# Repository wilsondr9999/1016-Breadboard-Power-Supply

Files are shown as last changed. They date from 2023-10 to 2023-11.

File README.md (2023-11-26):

# BreadBrick
#### The breadboard power supply *with flair*

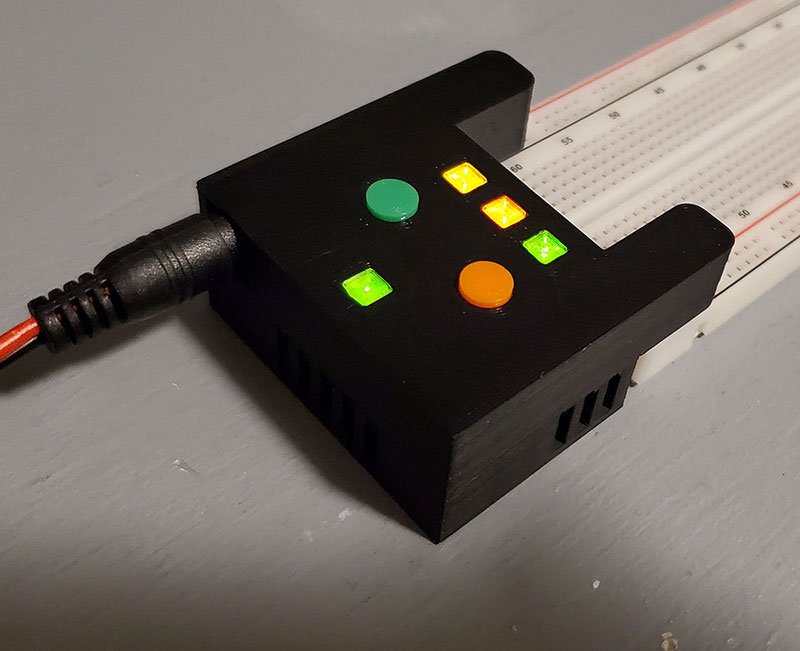
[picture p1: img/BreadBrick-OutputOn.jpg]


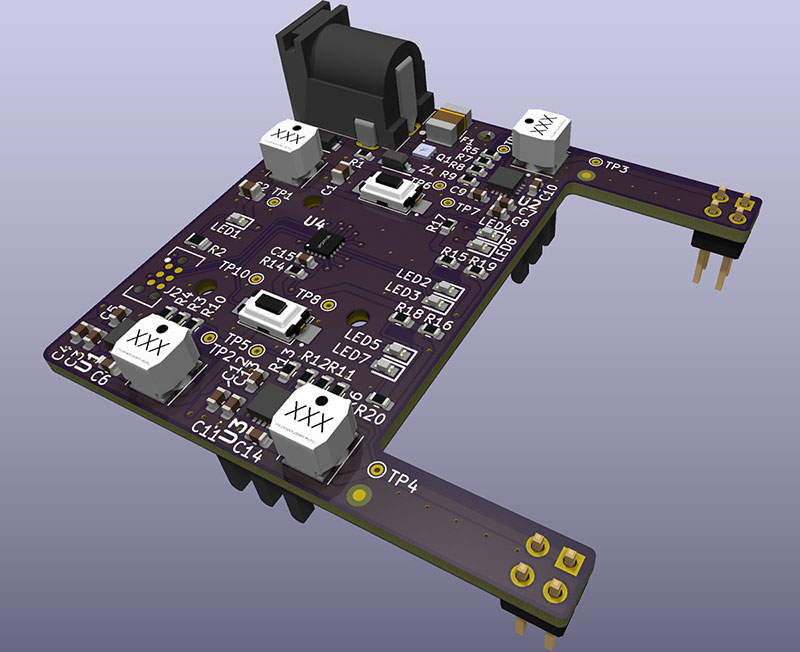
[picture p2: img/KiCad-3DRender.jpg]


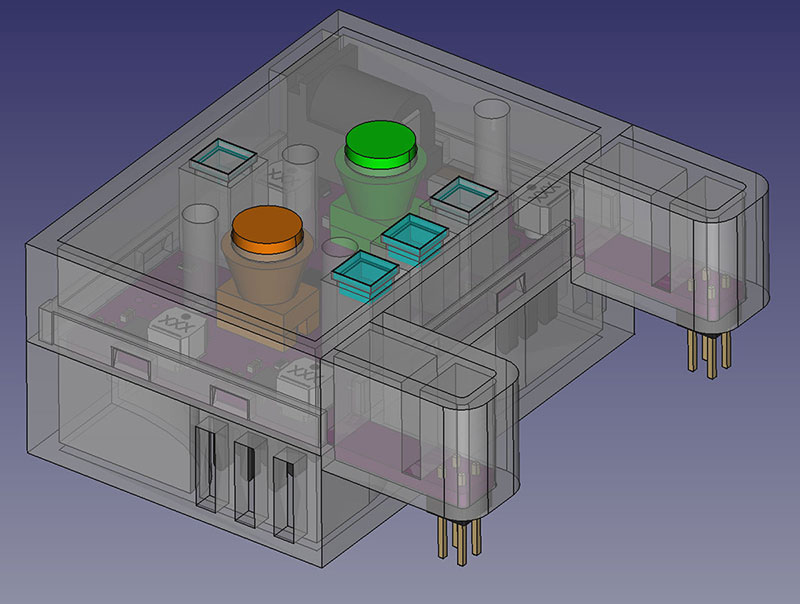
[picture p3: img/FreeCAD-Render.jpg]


## Why Another Breadboard Power Supply?

There's a million of these things out there, and they all work pretty much the same.  They plug in on one end of the breadboard and supply power to the voltage rails.  Many do 5V only, some have switchable 5V / 3.3V using jumpers.  Many use linear power regulators which are not terribly efficient.  Many have substantial voltage droop.  Many can't supply very much current.

I wanted something with a bit more, ummm, pizazz.  I wanted a case, not a bare PCB.  I wanted the ability to set the voltage independently for each rail, indicator lights for what voltages are set, up to 2A / 10W on each rail, and protection circuitry for those times when you plug something into the breadboard backwards.  And some efficiency so the thing doesn't get hot.

It took me a while, but I did it.

## Design

The design of the unit is actually not too complicated, there is an input section for protection and filtering, three [Texas Instruments TPS62130A](https://www.ti.com/product/TPS62130A) switching buck regulator circuits, two for the two power rails, and a 3rd that generates a dedicated 3.3V for the MCU, and an MCU section that uses the [STM32C011F4](https://www.st.com/en/microcontrollers-microprocessors/stm32c011f4.html).  The MCU is used to get user input from the buttons, drive the indicator LEDs, and control and monitor the rail regulators.

All components were selected for reasonable cost and wide availability.  However, the design is at the limit of what a hobbyist can successfully assemble.  While no parts smaller than 0603 are used, some ICs are QFN, and hand soldering these parts can be difficult for the hobbyists.  This board can be assembled by board assembly services at a reasonable cost.

## Tools and Software

Circuit design, schematics, and PCB layout were all done with [KiCad](https://www.kicad.org/).  Design of the case was done in [FreeCAD](https://www.freecad.org/).  Software code for the STM32C0 was written, compiled, and debugged using the [STM32CubeIDE](https://www.st.com/en/development-tools/stm32cubeide.html) development environment.

## Licensing

Several different licenses apply to this repository and the files within.

All schematics and circuit board designs in the project (all KiCad files), as well as all case designs (all FreeCAD files) are licensed under the [CERN Open Hardware License Version 2 - Strongly Reciprocal (CERN-OHL-S)](LICENSE-CERN-OHL-S).

All software and firmware code in the project (all ) are licensed under the [GNU Affero General Public License v3.0 (AGPL 3.0)](LICENSE-AGPL).

Documentation, Bill of Materials, pictures, and documentation (i.e. all other files not covered by the other two licenses above) are licensed under the [Creative Commons Attribution Share Alike 4.0 International License (CC-BY-SA-4.0)](LICENSE-CC-BY-SA-4.0).

These licenses form a very restrictive license for this design and this project.  This is done specifically for a reason.  That reason is that this project is for the hobbyist, and the hobbyist only.  It is for those people who want to have one of these units to be able to make one for themselves.  What it is not for is for some no-name company to produce thousands of them and make money when they had nothing to do with the design and the hard work.  These licenses force anyone who wants to do that to share anything and everything that they derive from this work so that the community and the hobbyists have it also.

## Specifications
- Input Voltage: 7V - 17V
- DC Barrel Jack: 2.5mm ID x 5.5mm OD, Center pin is positive (+)
- Max Input Current: 2A
- Output Voltage: 5V +/- 0.05V, 3.3V +/- 0.05V, switchable per rail
- Output Voltage Ripple: 25 mV at 2A load
- Max Output Current: 2A per rail
- Typical Efficiency: 88.0% at 12V input and 5V / 1A output
- Worst-Case Efficiency: 84.0% at 17V input and 3.3V / 2A output
- Worst-Case heat sink temperature: 51.1 C at full 2A load

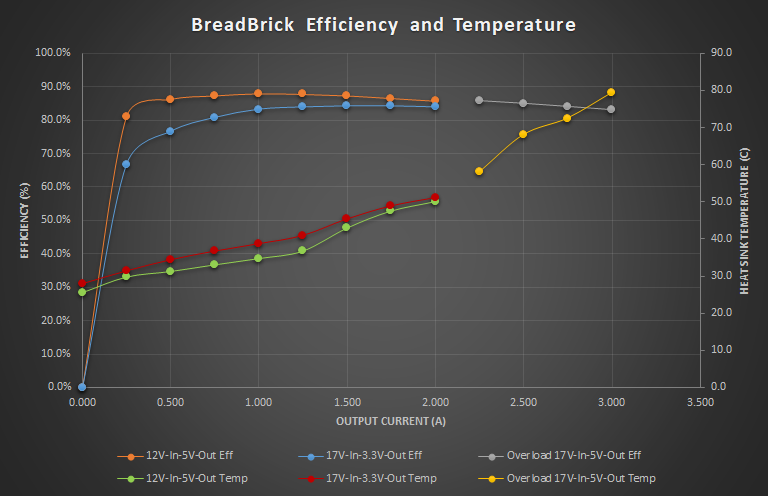
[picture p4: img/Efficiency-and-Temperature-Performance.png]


## How To Build
#### Ordering the PCB
To order this PCB, you can submit the [Fabrication Exports.zip](KiCAD%20Project/Fabrication%20Exports/Fabrication%20Exports.zip) file (located in [KiCAD Project/Fabrication Exports/](KiCAD%20Project/Fabrication%20Exports/)) to your favorite PCB manufacturing company.  This is a 2 layer board so costs should be low.
#### Ordering the Stencil
If you want to assemble the board yourself, especially if you want to use a reflow oven, you can order a stencil using the [1016 Breadboard Power Supply-F_Paste.gbr](KiCAD%20Project/Fabrication%20Exports/1016%20Breadboard%20Power%20Supply-F_Paste.gbr) gerber layer.  This layer includes 2.5mm alignment pins on two corners, these are sized and located to fit on the [solder stencil jig](FreeCAD%20Project/Parametric%20Solder%20Stencil%20Jig/1016%20v2%20Parametric%20Solder%20Stencil%20Jig.3mf) that can be 3D-printed.  If instead you are having a PCB manufacturer assemble the SMD components for you, you do not need the solder stencil.
#### Ordering Parts
If you're assembling yourself, you'll need to order parts.  The [1016 Breadboard Power Supply.csv](KiCAD%20Project/BOM/1016%20Breadboard%20Power%20Supply.csv) file located in the [KiCAD Project/BOM/](KiCAD%20Project/BOM/) folder contains all parts and manufacturer part numbers.
#### Assembling the PCB
The [ibom.html](KiCAD%20Project/BOM/ibom.html) file located in the [KiCAD Project/BOM/](KiCAD%20Project/BOM/) folder is generated from the [KiCad Interactive BOM plug-in](https://github.com/openscopeproject/InteractiveHtmlBom), and can help you mark which parts have been placed on the board prior to reflow.

Be very careful placing the LEDs.  The silkscreen marks pin 1 of the LED, but in accordance with the [datasheets](Datasheets/[DS-006]%20Wurth%20Elektronik%20150060VS75003.pdf) for the Wurth Elektronik LEDs, the pin 1 marking is NOT the cathode as would normally be expected.

After placing components, reflow the board in a reflow oven, hot plate, or use a hot air station.
#### Through-Hole Components
You will need to solder three through-hole components -- the DC power jack (PJ-102B), and the 2x2 pin headers (J3/J4).
#### Heat Sinks
The two heat sinks are glued onto the back side of the board using thermal adhesive.  Note that this is thermal adhesive (glue), not just an ordinary thermal compound or thermal paste.  The adhesive is required, there is no other mechanical support for the heat sinks.  I successfully used the [Gennel G109 Thermal Conductive Glue](https://www.amazon.com/dp/B072MSXHJD?psc=1&ref=ppx_yo2ov_dt_b_product_details).
#### 3D Printing the Case
The case can be 3D printed using the [Case Top-Bottom.3mf](FreeCAD%20Project/Case/STL/Case%20Top-Bottom.3mf), [Button.3mf](FreeCAD%20Project/Case/STL/Button.3mf), and [LED Lens.3mf](FreeCAD%20Project/Case/STL/LED%20Lens.3mf) files and [PrusaSlicer](https://www.prusa3d.com/page/prusaslicer_424/), or if you want to slice the .stl files yourself, the .stl files are also included in the [FreeCAD Project/Case/STL](FreeCAD%20Project/Case/STL/) folder.  Printing settings are as follows:
- 0.12mm Layer Height
- 0.4mm Nozzle
- PETG material, do not use PLA.  The snap-together design needs a flexible plastic, PLA is too brittle and will likely break when trying to snap together the case.  Also, PLA is not as temperature-resistant as PETG, and the heat sinks could cause problems with PLA.
- For the LED lenses, you will need a clear PETG filament.  I have had good results with [PolyMaker PolyLite Clear PETG](https://us.polymaker.com/products/polylite-petg?variant=41266031099961).
- Supports are not required, but both case halves should be printed with their flat surface on the print bed.  You may need to turn the upper case half so that the flat top is on the print bed.  The LED lenses need to be turned so that the larger side is down on the print bed.
- The upper case half prints with a thin bridge covering the LED lens holes, you will need to clean out the bridges with a hobbyist knife prior to inserting the LED lenses.
- It is critical that the buttons are printed to accurate dimensions as the clearances and travel are very small.  Print the buttons at a very slow speed with adequate time for each layer to cool to prevent any warping or distortion.  The .3mf file already has these settings pre-set.
#### Programming Firmware to the STM32
The STM32C011F4 firmware is the [1016 Breadboard Power Supply.elf](STM32%20Project/Debug/1016%20Breaadboard%20Power%20Supply.elf) file located in the [(STM32 Project/Debug/]((STM32%20Project/Debug/) folder.  This can be programmed to the STM32C011F4 using the [ST-Link/V2](https://www.st.com/en/development-tools/st-link-v2.html) debugger and the [Tag-Connect ARM20-CTX SWD Solution](https://www.tag-connect.com/debugger-cable-selection-installation-instructions/st-link-v2#49_126_145).  The 6-pin Tag-Connect connector connects with the J2 connector on the PCB, and the [STM32CubeProgrammer](https://www.st.com/en/development-tools/stm32cubeprog.html) software can write the firmware to the MCU.

Note that if you order the Tag-Connect SWD solution, you need the "No-Legs" version of the package that includes the TC-2030-IDC-NL cable.  The version of the cable with legs (TC-2030-IDC) will not properly fit this PCB.
#### Assembling the Unit
Once the PCB has been populated and soldered with the SMD and THT components, the heat sinks are attached with the thermal adhesive, and the case parts have been printed you can assemble the entire unit.
- Turn the upper half of the case upside down, and insert the two buttons, aligning the base of the buttons so that they will fit over the SMD switches on the PCB.
- Place the PCB into the top side of the case with the components towards the buttons and the heat sinks protruding.  Ensure the base of the buttons goes over the SMD switches on the PCB.  Hold the PCB against the support columns with your fingers.
- Test the buttons on the other side of the case and ensure you can feel them actuate the switches and that the switches are NOT pressed when the PCB is seated against the support columns.
- If the switches are not getting pressed when you press the button, the buttons dimensions are too small.  Re-check your print settings.
- If the switches are getting pressed before the PCB is seated against the support columns, the buttons dimensions are too large.  Re-check your print settings.
- Once you are confident that the buttons are the correct size and will work, remove the PCB from the top case half.
- Tape the buttons in place on the top side.  Fold the tape around the protruding button so that the button is at the top of it's travel (most protrusion).
- Insert the PCB into the case bottom with the components up and the heat sinks down.  The heat sinks will fit inside the cooling passages, and the holes in the PCB will fit on the support pins.
- Carefully fit the top half with the taped buttons onto the bottom half, and carefully get the two halves to mate and snap together.
- Remove the tape from the buttons and re-check that the buttons are working properly.  If you need to get the case apart again, you will need to use a [spudger](https://www.amazon.com/MMOBIEL-Pieces-Professional-Spudger-Toolkit/dp/B00UNBTM5U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) to pry the case apart.

## Using the Breadboard Power Supply
Plug the unit into your breadboard into the power rails.  As you're looking at the unit, the power arms/leads should point towards your right.  In this position, the TOP pins of each rail (furthest away from you) are the positive voltage, the BOTTOM pins of each rail (closest to you) are the reference voltage (ground).  Orient your breadboard so that the red/positive row of pins aligns with the positive pin of the unit (away from you).  If your breadboard is turned 180 degrees, the colors of the power rails will be opposite, and will cause confusion.

Power the unit using a DC barrel jack and power supply.  The jack is a standard 2.5mm x 5.5mm DC barrel jack, the center pin is the positive lead.  The unit has reverse power protection, so if your power supply uses ground for the center pin, you will not damage the unit, but it will not power on.  Your power supply should be between 7V and 17V output, and should provide at least 24W of power.  The standard supply that the unit was designed for is a [12V, 2A supply](https://www.amazon.com/Chanzon-Switching-Adapter-100-240V-Transformer/dp/B07HNL5D56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).  

Once the unit is powered on, it will self-test all LEDs.  You should see them sequentially light.

The left-most LED is the power-on LED, and indicates that input power is being received and is the correct voltage and polarity.  The LED remains green at all times when input power is supplied.

The top and bottom right-most LEDs indicate what voltage has been selected for the top rail and the bottom rail, respectively.  The LED is green when the rail has been selected for 5V output.  The LED is yellow when the rail has been selected for 3.3V output.

To configure the voltage setting, use the top-most button (colored green in the FreeCAD drawings).  Each press of the button cycles between the 4 combinations of rail voltages as follows:
1. Both rails 5V (LEDs green/green).
2. Top rail 3.3V / bottom rail 5V (LEDs yellow/green).
3. Top rail 5V / bottom rail 3.3V (LEDs green/yellow).
4. Both rails 3.3V (LEDs yellow/yellow).

Once you have selected the required voltage for your breadboard, turn the output on by pressing the bottom-most button (colored orange in the FreeCAD drawings).  The middle LED on the right will light orange to indicate that the output is on.  The unit begins monitoring the output power 50 msec after the output is turned on, and monitors the "Power Good" signal from both rail regulators.  If the output is subjected to a short circuit, an overcurrent condition, or the regulator temperatures get too high, the "power no good" signal from the regulators will be sensed and the MCU will turn off the output power, turn off all LEDs, and blink the middle LED red for 5 seconds.  The unit will then reset with the output power off.  This error condition can also occur if the input power source has problems, including undervoltage.  If this occurs, check the ratings on your input power source.

Press the bottom-most button again to turn the output power off on both rails.

The voltage configuration for the rails cannot be changed when the output is on.  When the output is on, pressing the top-most button will have no effect.  You must turn the output off using the bottom-most button before the voltage configuration can be changed.

## Caveats
The unit does **NOT** remember your voltage configuration setting between power cycles.  When input power is cycled, the unit will start up in a 5V/5V configuration.  If your breadboard needs 3.3V power on one or both of the rails, you will need to double-check and change the voltage configuration on each power-up before you turn the output power on.

Enjoy the unit, and happy breadboarding!

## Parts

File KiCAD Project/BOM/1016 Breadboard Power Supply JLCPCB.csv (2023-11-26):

Comment | Designator | Footprint | JLCPCB Part #
Pi Filter Capacitor | C1, C2 | Capacitor_SMD:C_0805_2012Metric | C602037
Input Capacitor | C3, C7, C11 | Capacitor_SMD:C_0603_1608Metric | C96446
Bypass Capacitor | C4, C8, C12, C15 | Capacitor_SMD:C_0603_1608Metric | C1590
Startup Capacitor | C5, C9, C13 | Capacitor_SMD:C_0603_1608Metric | C519423
Output Capacitor | C6, C10, C14 | Capacitor_SMD:C_0603_1608Metric | C159801
TVS Suppression Diode | CR1 | SOD-123F_LTF | C3719828
PTC Resettable Fuse | F1 | FUSE_SMD1812B110TF_YAG | C269149
Pi Filter Inductor | L1, L2, L3, L4 | VLS5045EX330M | C434831
Power On LED | LED1, LED4, LED5 | 1016:LEDC1608X80N | C965852
Error LED | LED2 | 1016:LEDC1608X80N | C965799
Output LED | LED3 | 1016:LEDC1608X80N | C965801
3V3 Top Rail LED | LED6, LED7 | 1016:LEDC1608X80N | C965852
RPP MOSFET | Q1 | 1016:BUK6D12060PX | C503628
RPP Zener Resistor | R1 | Resistor_SMD:R_0603_1608Metric | C185353
Power On LED Resistor | R2 | Resistor_SMD:R_0805_2012Metric | C114572
Feedback Rtop | R3 | Resistor_SMD:R_0603_1608Metric | C14675
Feedback Rbot | R4 | Resistor_SMD:R_0603_1608Metric | C185339
Power Good Pull-Up Resistor | R5, R6, R10, R14 | Resistor_SMD:R_0603_1608Metric | C98220
Feedback Rtop | R7, R11 | Resistor_SMD:R_0603_1608Metric | C123420
Feedback Rbot | R8, R12 | Resistor_SMD:R_0603_1608Metric | C273741
Feedback Rbot | R9, R13 | Resistor_SMD:R_0603_1608Metric | C273777
Error LED Resistor | R15 | Resistor_SMD:R_0603_1608Metric | C227839
Output LED Resistor | R16 | Resistor_SMD:R_0603_1608Metric | C185331
5V Top Rail LED Resistor | R17, R18 | Resistor_SMD:R_0603_1608Metric | C227706
3V3 Top Rail Resistor | R19, R20 | Resistor_SMD:R_0603_1608Metric | C273768
Output Enable Btn | S1, S2 | PTS636SK25JSMTRLFS | C2800965
MCU Regulator | U1, U2, U3 | QFN50P300X300X100-17N-D | C337502
Microcontroller | U4 | UFQFPN20_3X3_STM | C5456188
RPP Zener Diode | Z1 | SOD3716X145N | C85181

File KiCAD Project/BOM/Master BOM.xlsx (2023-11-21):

1016 Breadboard Power Supply Master BOM
Item ID | Sheet | Description | Spec | Sch Ref | Qty | Value | DNP | Height | Manufacturer | Mfr Part Num | Mouser Part Num | LCSC Part Num | [4] DL SF3 | [5] Import | [6] Place | [7] Update
1 | Input Power | Input Power Jack | 2.5mm, 2.5A, 24V | J1 | 1 | PJ-102B | 0 | 11 | CUI Devices | PJ-102B | 490-PJ-102B |  | X | X | X | X
2 | Input Power | PTC Resettable Fuse | Ihold 3A, Itrip 6A | F1 | 1 | PTC 3A | 0 | 1.6 | Yageo-Brightking | SMD1812B300TFT | 603-SMD1812B300TFT | C269149 | X | X | X | X
3 | Input Power | TVS Suppression Diode | Vrw 17V, Vcl 27V | CR1 | 1 | SMF17CA | 0 | 1 | Littlefuse | SMF17CA | 576-SMF17CA | C3719828 | X | X | X | X
4 | Input Power | RPP MOSFET | P-Ch 60V 8A | Q1 | 1 | BUK6D120-60PX | 0 | 0.65 | Nexperia | BUK6D120-60PX | 771-BUK6D120-60PX | C503628 | X | X | X | X
5 | Input Power | RPP Zener Diode | 5.1V 5% 500mW | Z1 | 1 | MMSZ5231B-7-F | 0 | 1.05 | Diodes Inc | MMSZ5231B-7-F | 621-MMSZ5231B-7-F | C85181 | X | X | X | X
6 | Input Power | Power On LED | Grn 570nm | LED1 | 1 | 150060VS75003 | 0 | 0.7 | Wurth Elektronik | 150060VS75003 | 710-150060VS75003 | C965852 | X | X | X | X
7 | Input Power | RPP Zener Resistor | 1K91 100mW | R1 | 1 | 1K91 | 0 | 0.45 | Yageo | RC0603FR-071K91L | 603-RC0603FR-071K91L | C185353 | - | - | X | X
8 | Input Power | Power On LED Resistor | 2K 125mW | R2 | 1 | 2K | 0 | 0.5 | Yageo | RC0805FR-072KL | 603-RC0805FR-072KL | C114572 | - | - | X | X
9 | Input Power | Pi Filter Capacitor | 22µ 25V | C1, C2 | 2 | 22µ | 0 | 1.25 | Samsung | CL21A226MAYNNNE | 187-CL21A226MAYNNNE | C602037 | - | - | X | X
10 | Input Power | Pi Filter Inductor | 2.2µ 4.7A 22mΩ | L1 | 1 | 2.2µ | 0 | 4.5 | TDK | VLS5045EX-2R2N | 810-VLS5045EX-2R2N | C434831 | X | X | X | X
11 | MCU Power Regulator | Regulator for MCU 3V3 | 2.5MHz Buck Reg | U1 | 1 | TPS62130A | 0 | 1 | Texas Instruments | TPS62130ARGTR | 595-TPS62130ARGTR | C337502 | X | X | X | X
12 | MCU Power Regulator | Feedback Rtop | 100K 100mW | R3 | 1 | 100K | 0 | 0.45 | Yageo | RC0603FR-07100KL | 603-RC0603FR-07100KL | C14675 | - | - | X | X
13 | MCU Power Regulator | Feedback Rbot | 31K6 100mW | R4 | 1 | 31K6 | 0 | 0.45 | Yageo | RC0603FR-0731K6L | 603-RC0603FR-0731K6L | C185339 | - | - | X | X
14 | MCU Power Regulator | Input Capacitor | 10µ 25V | C3 | 1 | 10µ | 0 | 0.8 | Samsung | CL10A106MA8NRNC | 187-CL10A106MA8NRNC | C96446 | - | - | X | X
15 | MCU Power Regulator | Bypass Capacitor | 100n 25V | C4 | 1 | 100n | 0 | 0.8 | Samsung | CL10B104KA8NNNC | 187-CL10B104KA8NNNC | C1590 | - | - | X | X
16 | MCU Power Regulator | Startup Capacitor | 3n3 25V | C5 | 1 | 3n3 | 0 | 0.8 | Yageo | CC0603KRX7R8BB332 | 603-CC603KRX7R8BB332 | C519423 | - | - | X | X
17 | MCU Power Regulator | Output Capacitor | 22µ 6V3 | C6 | 1 | 22µ | 0 | 0.8 | Samsung | CL10A226MQ8NRNE | 187-CL10A226MQ8NRNE | C159801 | - | - | X | X
18 | MCU Power Regulator | Output Discharge Resistor | 10K 100mW | R10 | 1 | 10K | 0 | 0.45 | Yageo | RC0603FR-0710KL | 603-RC0603FR-0710KL | C98220 | - | - | X | X
19 | Rail T Power Regulator | Regulator for Top Rail | 2.5MHz Buck Reg | U2 | 1 | TPS62130 | 0 | 1 | Texas Instruments | TPS62130RGTR | 595-TPS62130RGTR | C43590 | X | X | X | X
20 | Rail T Power Regulator | Feedback Rtop | 220K 100mW | R7 | 1 | 220K | 0 | 0.45 | Yageo | RC0603FR-07220KL | 603-RC0603FR-07220KL | C123420 | - | - | X | X
21 | Rail T Power Regulator | Feedback Rbot1 | 42K2 100mW | R8 | 1 | 42K2 | 0 | 0.45 | Yageo | RC0603FR-0742K2L | 603-RC0603FR-0742K2L | C273741 | - | - | X | X
22 | Rail T Power Regulator | Feedback Rbot2 | 28K 100mW | R9 | 1 | 28K | 0 | 0.45 | Yageo | RC0603FR-0728KL | 603-RC0603FR-0728KL | C273777 | - | - | X | X
23 | Rail T Power Regulator | Input Capacitor | 10µ 25V | C7 | 1 | 10µ | 0 | 0.8 | Samsung | CL10A106MA8NRNC | 187-CL10A106MA8NRNC | C96446 | - | - | X | X
24 | Rail T Power Regulator | Bypass Capacitor | 100n 25V | C8 | 1 | 100n | 0 | 0.8 | Samsung | CL10B104KA8NNNC | 187-CL10B104KA8NNNC | C1590 | - | - | X | X
25 | Rail T Power Regulator | Startup Capacitor | 3n3 25V | C9 | 1 | 3n3 | 0 | 0.8 | Yageo | CC0603KRX7R8BB332 | 603-CC603KRX7R8BB332 | C519423 | - | - | X | X
26 | Rail T Power Regulator | Output Capacitor | 22µ 6V3 | C10 | 1 | 22µ | 0 | 0.8 | Samsung | CL10A226MQ8NRNE | 187-CL10A226MQ8NRNE | C159801 | - | - | X | X
27 | Rail T Power Regulator | Output Discharge Resistor | 10K 100mW | R5 | 1 | 10K | 0 | 0.45 | Yageo | RC0603FR-0710KL | 603-RC0603FR-0710KL | C98220 | - | - | X | X
28 | Rail B Power Regulator | Regulator for Bottom Rail | 2.5MHz Buck Reg | U3 | 1 | TPS62130 | 0 | 1 | Texas Instruments | TPS62130RGTR | 595-TPS62130RGTR | C43590 | X | X | X | X
29 | Rail B Power Regulator | Feedback Rtop | 220K 100mW | R11 | 1 | 220K | 0 | 0.45 | Yageo | RC0603FR-07220KL | 603-RC0603FR-07220KL | C123420 | - | - | X | X
30 | Rail B Power Regulator | Feedback Rbot1 | 42K2 100mW | R12 | 1 | 42K2 | 0 | 0.45 | Yageo | RC0603FR-0742K2L | 603-RC0603FR-0742K2L | C273741 | - | - | X | X
31 | Rail B Power Regulator | Feedback Rbot2 | 28K 100mW | R13 | 1 | 28K | 0 | 0.45 | Yageo | RC0603FR-0728KL | 603-RC0603FR-0728KL | C273777 | - | - | X | X
32 | Rail B Power Regulator | Input Capacitor | 10µ 25V | C11 | 1 | 10µ | 0 | 0.8 | Samsung | CL10A106MA8NRNC | 187-CL10A106MA8NRNC | C96446 | - | - | X | X
33 | Rail B Power Regulator | Bypass Capacitor | 100n 25V | C12 | 1 | 100n | 0 | 0.8 | Samsung | CL10B104KA8NNNC | 187-CL10B104KA8NNNC | C1590 | - | - | X | X
34 | Rail B Power Regulator | Startup Capacitor | 3n3 25V | C13 | 1 | 3n3 | 0 | 0.8 | Yageo | CC0603KRX7R8BB332 | 603-CC603KRX7R8BB332 | C519423 | - | - | X | X
35 | Rail B Power Regulator | Output Capacitor | 22µ 6V3 | C14 | 1 | 22µ | 0 | 0.8 | Samsung | CL10A226MQ8NRNE | 187-CL10A226MQ8NRNE | C159801 | - | - | X | X
36 | Rail B Power Regulator | Output Discharge Resistor | 10K 100mW | R6 | 1 | 10K | 0 | 0.45 | Yageo | RC0603FR-0710KL | 603-RC0603FR-0710KL | C98220 | - | - | X | X
37 | MCU Control | Microcontroller | 48MHz ARM M0 | U4 | 1 | STM32C011F4U6TR | 0 | 0.55 | ST Micro | STM32C011F4U6TR | 511-STM32C011F4U6TR | C5456188 | X | X | X | X
38 | MCU Control | SWD Pogo Connector | 6-Pin SWD | J2 | 1 | TC2030-IDC | 0 | 0 | Tag-Connect | TC2030-IDC |  |  | X | X | X | X
39 | MCU Control | Output Enable | 50mA 12Vdc 250gf | S1 | 1 | Tactile Switch 6mm | 0 | 2.7 | C & K COMPONENTS | PTS636 SK25J SMTR LFS | 611-PTS636SK25JSMTRL | C2800965 | X | X | X | X
40 | MCU Control | Config Btn | 50mA 12Vdc 250gf | S2 | 1 | Tactile Switch 6mm | 0 | 2.7 | C & K COMPONENTS | PTS636 SK25J SMTR LFS | 611-PTS636SK25JSMTRL | C2800965 | X | X | X | X
41 | MCU Control | Error LED | Red 625nm | LED2 | 1 | 150060RS75003 | 0 | 0.7 | Wurth Elektronik | 150060RS75003 | 710-150060RS75003 | C965799 | X | X | X | X
42 | MCU Control | Output LED | Amber 605nm | LED3 | 1 | 150060AS75003 | 0 | 0.7 | Wurth Elektronik | 150060AS75003 | 710-150060AS75003 | C965801 | X | X | X | X
43 | MCU Control | 5V Top Rail LED | Green 570nm | LED4 | 1 | 150060VS75003 | 0 | 0.7 | Wurth Elektronik | 150060VS75003 | 710-150060VS75003 | C965852 | X | X | X | X
44 | MCU Control | 5V Bottom Rail LED | Yellow 590nm | LED5 | 1 | 150060YS75003 | 0 | 0.7 | Wurth Elektronik | 150060YS75003 | 710-150060YS75003 | C965802 | X | X | X | X
45 | MCU Control | 3V3 Top Rail LED | Green 570nm | LED6 | 1 | 150060VS75003 | 0 | 0.7 | Wurth Elektronik | 150060VS75003 | 710-150060VS75003 | C965852 | X | X | X | X
46 | MCU Control | 3V3 Bottom Rail LED | Yellow 590nm | LED7 | 1 | 150060YS75003 | 0 | 0.7 | Wurth Elektronik | 150060YS75003 | 710-150060YS75003 | C965802 | X | X | X | X
47 | MCU Control | Error LED Resistor | 365 100mW | R15 | 1 | 365 | 0 | 0.45 | Yageo | AC0603FR-07365RL | 603-AC0603FR-07365RL | C227839 | X | X | X | X
48 | MCU Control | Output LED Resistor | 402 100mW | R16 | 1 | 402 | 0 | 0.45 | Yageo | RC0603FR-07402RL | 603-RC0603FR-07402RL | C185331 | X | X | X | X
49 | MCU Control | 5V Top Rail LED Resistor | 210 100mW | R17 | 1 | 210 | 0 | 0.45 | Yageo | AC0603FR-07210RL | 603-AC0603FR-07210RL | C227706 | X | X | X | X
50 | MCU Control | 5V Bottom Rail LED Resistor | 210 100mW | R18 | 1 | 210 | 0 | 0.45 | Yageo | AC0603FR-07210RL | 603-AC0603FR-07210RL | C227706 | X | X | X | X
51 | MCU Control | 3V3 Top Rail LED Resistor | 887 100mW | R19 | 1 | 887 | 0 | 0.45 | Yageo | RC0603FR-07887RL | 603-RC0603FR-07887RL | C273768 | X | X | X | X
52 | MCU Control | 3V3 Bottom Rail LED Resistor | 887 100mW | R20 | 1 | 887 | 0 | 0.45 | Yageo | RC0603FR-07887RL | 603-RC0603FR-07887RL | C273768 | X | X | X | X
53 | MCU Control | Bypass Capacitor | 100n 25V | C15 | 1 | 100n | 0 | 0.8 | Samsung | CL10B104KA8NNNC | 187-CL10B104KA8NNNC | C1590 | - | - | X | X
54 | MCU Control | Nreset Pull-Up Resistor | 10K 100mW | R14 | 1 | 10K | 0 | 0.45 | Yageo | RC0603FR-0710KL | 603-RC0603FR-0710KL | C98220 | - | - | X | X
55 | Rail Output | Pin Header 2x2 | 2x2 Pin Hdr 2.54mm Gold | J3 | 1 | Pin Hdr 2x2 | 0 | 0.9 | Samtec | TSW-102-07-L-D | 200-TSW10207LD | C3346817 | - | - | X | X
56 | Rail Output | Pin Header 2x2 | 2x2 Pin Hdr 2.54mm Gold | J4 | 1 | Pin Hdr 2x2 | 0 | 0.9 | Samtec | TSW-102-07-L-D | 200-TSW10207LD | C3346817 | - | - | X | X
57 | Root | Heat Sink | 8.5mm x 8.5mm Al | HS1 | 3 | HSB01-080808 | 0 | 8 | CUI Devices | HSB01-080808 | 490-HSB01-080808 |  | X | X | X | X

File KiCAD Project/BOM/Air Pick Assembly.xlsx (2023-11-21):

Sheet: Parts List
1016 Breadboard Power Supply
Air Pick Assembly
 |  |  |  | Tape | Pin 1 | Part | AirPick
Reference | Qty | Manufacturer_Part_Number | Spec | Width | Orientation | Size | Tip | Tape
L1, L2, L3, L4 | 4 | VLS5045EX-2R2N | 2.2µH 4.7A 22mΩ | 12 | á | 5050 | 1/8
U1, U2, U3 | 3 | TPS62130ARGTR | 2.5MHz Buck Reg | 12 | ä | 3030 | 3/32
U4 | 1 | STM32C011F4U6TR | 48MHz ARM M0 | 12 | ä | 3030 | 3/32
C3, C7, C11 | 3 | CL10A106MA8NRNC | 10µ 25V | 8 | ¡ | 0603 | 3020
C4, C8, C12, C15 | 4 | CL10B104KA8NNNC | 100n 25V | 8 | ¡ | 0603 | 3020
C5, C9, C13 | 3 | CC0603KRX7R8BB332 | 3n3 25V | 8 | ¡ | 0603 | 3020
C6, C10, C14 | 3 | CL10A226MQ8NRNE | 22µ 6V3 | 8 | ¡ | 0603 | 3020
LED1, LED4, LED5 | 3 | 150060VS75003 | Grn 570nm | 8 | â | 0603 | 3020
LED2 | 1 | 150060RS75003 | Red 625nm | 8 | â | 0603 | 3020
LED3 | 1 | 150060AS75003 | Amber 605nm | 8 | â | 0603 | 3020
LED6, LED7 | 2 | 150060YS75003 | Yellow 590nm | 8 | â | 0603 | 3020
R1 | 1 | RC0603FR-071K91L | 1K91 100mW | 8 | ¡ | 0603 | 3020
R5, R6, R10, R14 | 1 | RC0603FR-0710KL | 10K 100mW | 8 | ¡ | 0603 | 3020
R15 | 1 | AC0603FR-07365RL | 365 100mW | 8 | ¡ | 0603 | 3020
R16 | 1 | RC0603FR-07402RL | 402 100mW | 8 | ¡ | 0603 | 3020
R17, R18 | 2 | AC0603FR-07210RL | 210 100mW | 8 | ¡ | 0603 | 3020
R19, R20 | 2 | RC0603FR-07887RL | 887 100mW | 8 | ¡ | 0603 | 3020
R3 | 1 | RC0603FR-07100KL | 100K 100mW | 8 | ¡ | 0603 | 3020
R4 | 1 | RC0603FR-0731K6L | 31K6 100mW | 8 | ¡ | 0603 | 3020
R7, R11 | 2 | RC0603FR-07220KL | 220K 100mW | 8 | ¡ | 0603 | 3020
R8, R12 | 2 | RC0603FR-0742K2L | 42K2 100mW | 8 | ¡ | 0603 | 3020
R9, R13 | 2 | RC0603FR-0728KL | 28K 100mW | 8 | ¡ | 0603 | 3020
C1, C2 | 2 | CL21A226MAYNNNE | 22µ 25V | 8 | ¡ | 0805 | 4030
F1 | 1 | SMD1812B300TFT | Ihold 3A, Itrip 6A | 12 | ¡ | 1812 | 3/32
R2 | 1 | RC0805FR-072KL | 2K 125mW | 8 | ¡ | 0805 | 4030
CR1 | 1 | SMF17CA | Vrw 17V, Vcl 27V | 8 | ¡ | 3020 | 6040
Q1 | 1 | BUK6D120-60PX | P-Ch 60V 8A | 8 | ä | 2020 | 6040
Z1 | 1 | MMSZ5231B-7-F | 5.1V 5% 500mW | 8 | â | 2716 | 6040
J1 | 1 | PJ-102B | 2.5mm, 2.5A, 24V |  |  |  | #N/A
J3, J4 | 2 | TSW-102-07-L-D | 2x2 Pin Hdr 2.54mm |  |  |  | #N/A
S1, S2 | 2 | PTS636 SK25J SMTR LFS | 50mA 12Vdc 250gf | 16 | ¡ | ----- | #N/A

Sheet: AirPick Tips
AirPick Tips
 | Outer | Inner | Outer
Tip ID | Thou In | Thou In | Tnths mm | Tip ID
0803 | 8 | 3 | 2.032 | 0803
1005 | 10 | 5 | 2.540 | 1005
2010 | 20 | 10 | 5.080 | 2010
3020 | 30 | 20 | 7.620 | 3020
4030 | 40 | 30 | 10.160 | 4030
6040 | 60 | 40 | 15.240 | 6040
8060 | 80 | 60 | 20.320 | 8060
3/32 | 94 |  | 23.876 | 3/32
1/8 | 125 |  | 31.750 | 1/8
1/4 | 250 |  | 63.500 | 1/4
3/8 | 375 |  | 95.250 | 3/8
1/2 | 500 |  | 127.000 | 1/2

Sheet: Size Conversions
Size Conversions
 | Min Dim | Min Dim | Min Dim
Size | Thou In | Tnths mm | Tnths mm
0603 | 30 |  | 7.62
1812 | 120 |  | 30.48
0805 | 50 |  | 12.7
2716 |  | 16 | 16
3020 |  | 20 | 20
2020 |  | 20 | 20
3030 |  | 30 | 30
5050 |  | 50 | 50

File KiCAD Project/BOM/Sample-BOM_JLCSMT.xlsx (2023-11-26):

Comment | Designator | Footprint | JLCPCB Part #（optional）
100uF | C1 | CAP-SMD_L3.5-W2.8 | C16133
15K | R5,R6 | R0603 | C22809
DC-005-20A_C136744 | DC1 | DC-IN-TH_DC-005-20A | C136744
Header-Female-2.54_1x8 | P2,P3 | HDR-TH_8P-P2.54-V | C27438
K2-1102DP-C4SW-04 | SW1 | KEY-TH_4P-L6.0-W6.0-P4.50-LS6.5 | C110153
ATMEGA328P-PU | U1 | DIP-28_L34.6-W7.3-P2.54-LS10.2-BL | C33901
670688000 | USB1 | USB-B-TH_67068-8000 | C114097

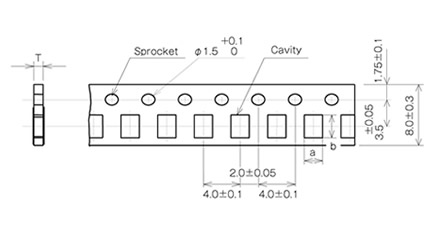
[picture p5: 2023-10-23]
KiCAD Project/BOM/SMD Tape Images/tech_img_tape02_01.jpg

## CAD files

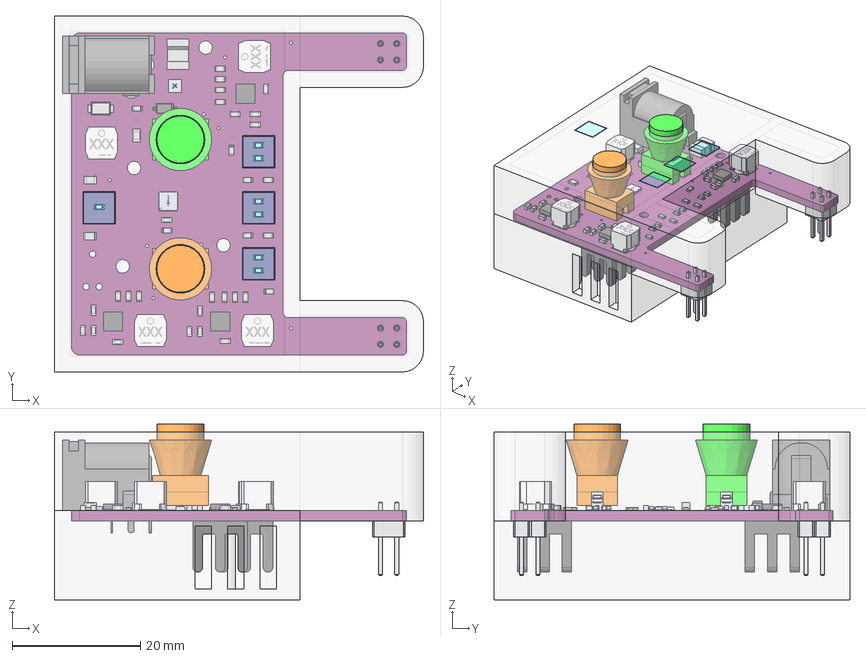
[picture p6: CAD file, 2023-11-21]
FreeCAD Project/Case/1016 Case v2.FCStd
57.6 x 55.6 x 27.5 mm
Body - Case Bottom
Pcb_6678
VLS5045EX_C(3Dmodel) x 4
VLS5045EX_T(3Dmodel) x 4
VLS5045EX_T(3Dmodel)001 x 4
R7_R_0603_1608Metric_f2ceac092466 x 19
R2_R_0805_2012Metric_371003b801f0
J1_CUI_DEVICES_PJ-102B_df1f8035472e
150060GS75000 x 7
150060GS75001 x 7
150060GS75002 x 7
150060GS75003 x 7
C12_C_0603_1608Metric_5ff17418a113 x 13
PTS636 SK25J SMTR LFS x 2
PTS636 SK25J SMTR LFS001 x 2
PTS636 SK25J SMTR LFS002 x 2
PTS636 SK25J SMTR LFS003 x 2
PTS636 SK25J SMTR LFS004 x 2
PTS636 SK25J SMTR LFS005 x 2
PTS636 SK25J SMTR LFS006 x 2
PTS636 SK25J SMTR LFS007 x 2
C2_C_0805_2012Metric_c8aa68a57114 x 2
BODY-QFN x 3
6B1406E0-4718-44C7-AF55-B7F83AEA0728
6B1406E0-4718-44C7-AF55-B7F83AEA0729
6B1406E0-4718-44C7-AF55-B7F83AEA0730
6B1406E0-4718-44C7-AF55-B7F83AEA0731
6B1406E0-4718-44C7-AF55-B7F83AEA0732
6B1406E0-4718-44C7-AF55-B7F83AEA0733
6B1406E0-4718-44C7-AF55-B7F83AEA0734
6B1406E0-4718-44C7-AF55-B7F83AEA0735
6B1406E0-4718-44C7-AF55-B7F83AEA0736
6B1406E0-4718-44C7-AF55-B7F83AEA0737
6B1406E0-4718-44C7-AF55-B7F83AEA0738
6B1406E0-4718-44C7-AF55-B7F83AEA0739
6B1406E0-4718-44C7-AF55-B7F83AEA0740
6B1406E0-4718-44C7-AF55-B7F83AEA0741
6B1406E0-4718-44C7-AF55-B7F83AEA0742
6B1406E0-4718-44C7-AF55-B7F83AEA0743
6B1406E0-4718-44C7-AF55-B7F83AEA0744
6B1406E0-4718-44C7-AF55-B7F83AEA0745
6B1406E0-4718-44C7-AF55-B7F83AEA0746
6B1406E0-4718-44C7-AF55-B7F83AEA0747
6B1406E0-4718-44C7-AF55-B7F83AEA0748
SOT1220 Body
SOT1220 Lead
SOT1220 Lead001
SOT1220 Lead002
SOT1220 Lead003
SOT1220 Lead004
SOT1220 Lead005
SOT1220 Lead006
SOT1220 Lead007
SOT1220 Lead008
SOT1220 Lead009
SOT1220 Lead010
SOT1220 Lead011
SOT1220 Lead012
SOT1220 Lead013
SOT1220 Lead014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

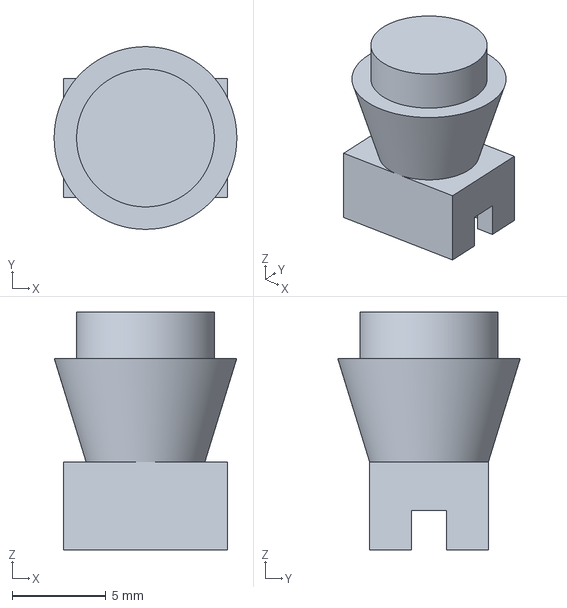
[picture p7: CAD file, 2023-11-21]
FreeCAD Project/Case/STL/Button.3mf
9.77 x 9.77 x 12.7 mm

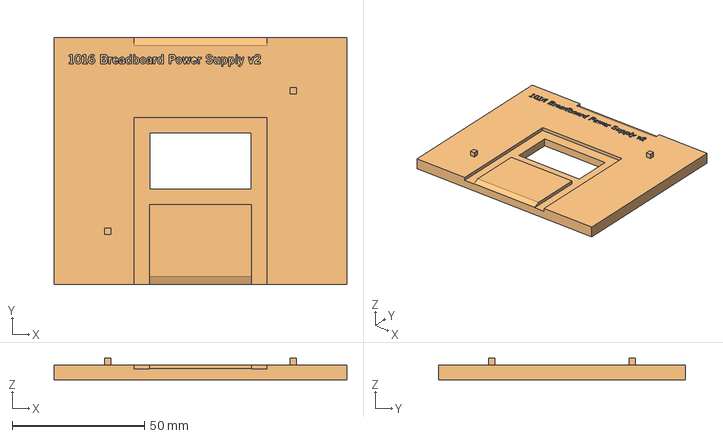
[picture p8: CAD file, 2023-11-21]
FreeCAD Project/Parametric Solder Stencil Jig/1016 v2 Parametric Solder Stencil Jig.FCStd
110.9 x 93.6 x 8.17 mm
Pocket004 (Meshed)

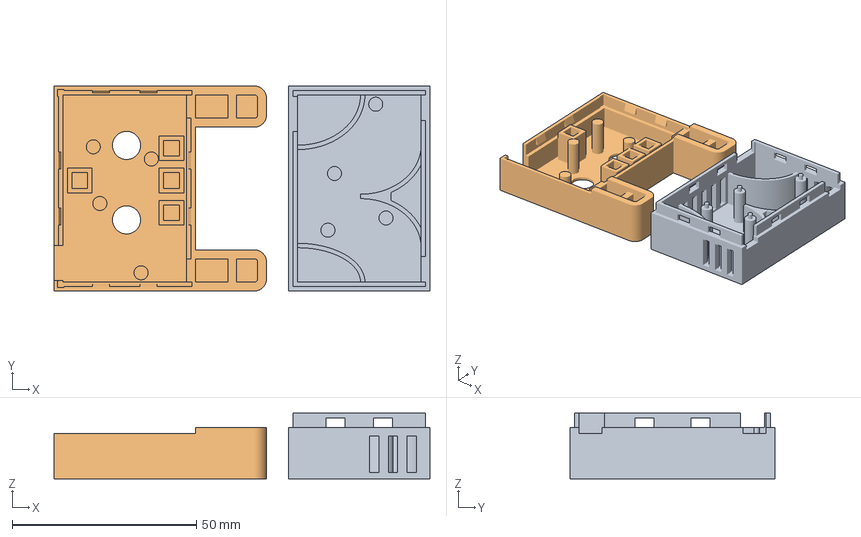
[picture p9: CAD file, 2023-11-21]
FreeCAD Project/Case/STL/Case Top-Bottom.3mf
102.0 x 55.6 x 17.8 mm
Mesh-STL - Case Bottom.stl
Mesh-STL - Case Top.stl

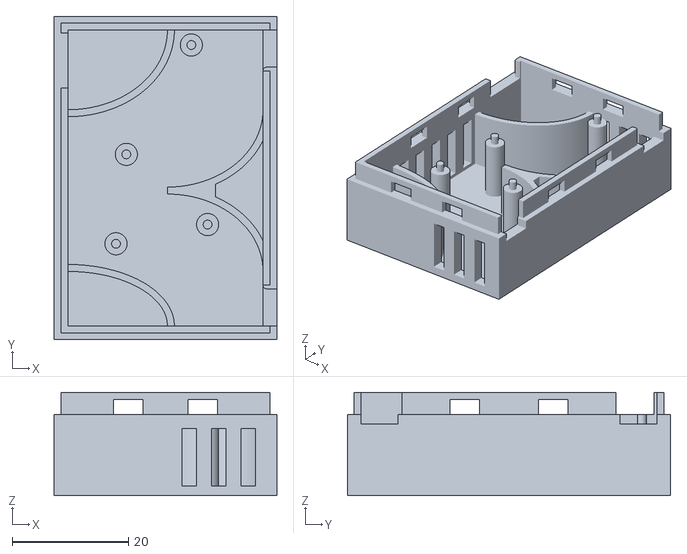
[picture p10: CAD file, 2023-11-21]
FreeCAD Project/Case/STL/Mesh-STL - Case Bottom.stl
38.3 x 55.6 x 17.8

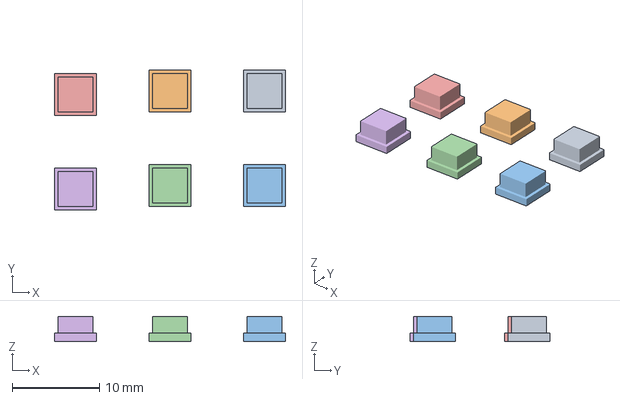
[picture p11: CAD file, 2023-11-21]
FreeCAD Project/Case/STL/LED Lens.3mf
26.5 x 16.1 x 2.88 mm

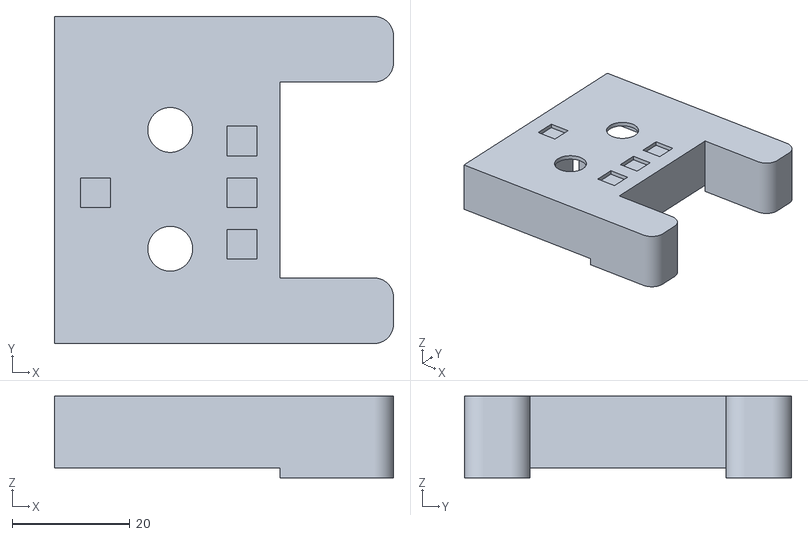
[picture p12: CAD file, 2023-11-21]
FreeCAD Project/Case/STL/Mesh-STL - Case Top.stl
57.6 x 55.6 x 13.9

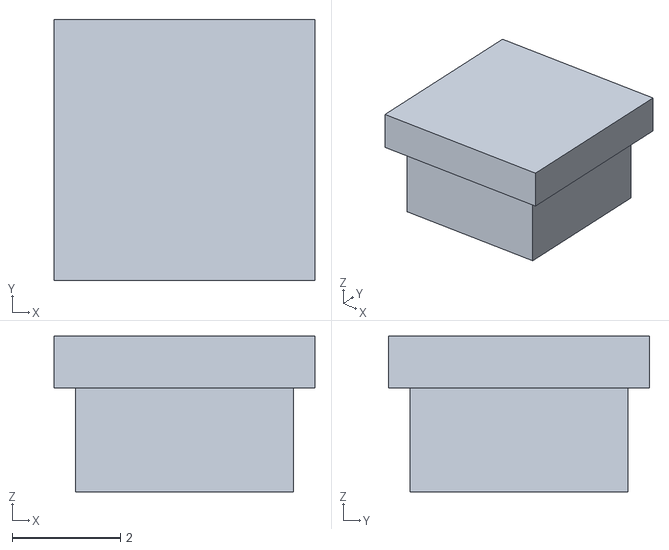
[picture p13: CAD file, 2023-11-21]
FreeCAD Project/Case/STL/Mesh-STL - LED Lens.stl
4.83 x 4.83 x 2.88

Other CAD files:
FreeCAD Project/Case/STL/Mesh-STL - Button.stl
FreeCAD Project/Parametric Solder Stencil Jig/1016 v2 Parametric Solder Stencil Jig.3mf
FreeCAD Project/Parametric Solder Stencil Jig/1016 v2 Parametric Solder Stencil Jig.stl

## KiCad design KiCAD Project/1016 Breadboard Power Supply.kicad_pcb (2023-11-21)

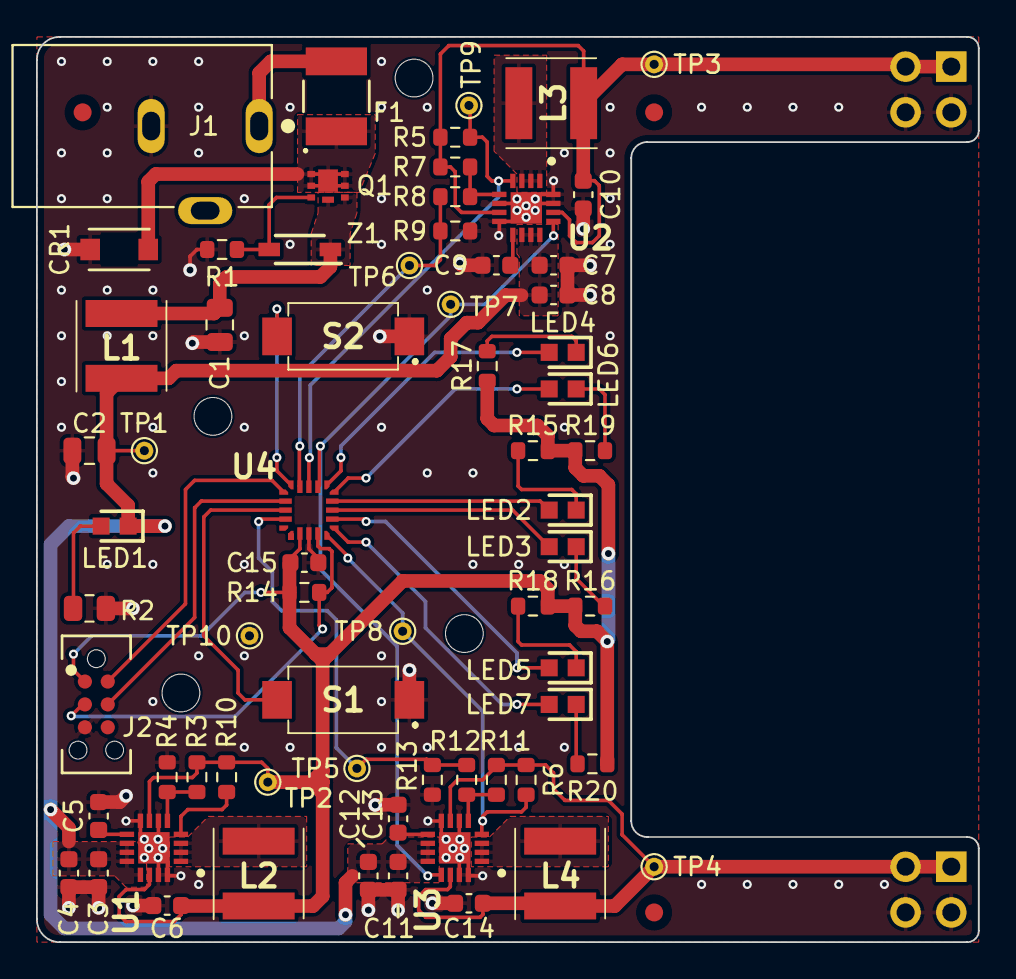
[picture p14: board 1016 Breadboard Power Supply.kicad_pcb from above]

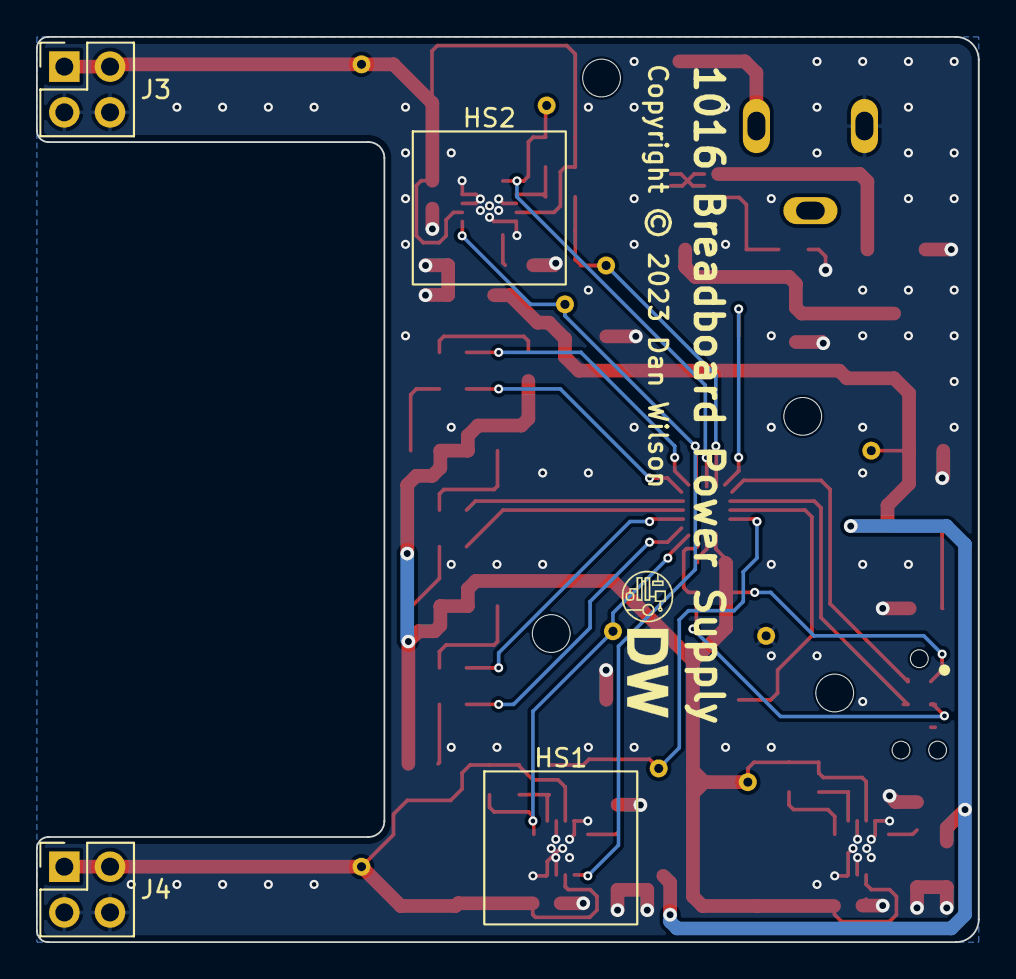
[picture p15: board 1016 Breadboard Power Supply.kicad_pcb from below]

Board: 2 copper layers, 52.3 x 50.3 mm, 82 parts (5 on the bottom side), 42 nets.

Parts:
C1, C2: 22µ; C_0805_2012Metric
C3, C7, C11: 10µF; C_0603_1608Metric
C4, C8, C12, C15: 100n; C_0603_1608Metric
C5, C9, C13: 3n3; C_0603_1608Metric
C6, C10, C14: 22µ; C_0603_1608Metric
CR1: SMF17CA; SOD-123F_LTF
F1: SMD1812B110TF; FUSE_SMD1812B110TF_YAG
FID1, FID2, FID3: Fiducial; Fiducial_1mm_Mask2mm
H1, H2, H3, H4: MountingHole; MountingHole_2.1mm
HS1, HS2: Heat Sink; HSB01-080808
J1: PJ-102B; CUI_PJ-102B
J2: TC2030-IDC-NL; CONN_TC2030-IDC-NL_TGC
J3, J4: Pin Hdr 2x2; PinHeader_2x02_P2.54mm_Vertical
L1, L2, L3, L4: VLS5045EX-2R2N; VLS5045EX330M
LED1, LED4, LED5: 150060VS75003; LEDC1608X80N
LED2: 150060RS75003; LEDC1608X80N
LED3: 150060AS75003; LEDC1608X80N
LED6, LED7: 150060YS75003; LEDC1608X80N
P1: DW_PCB_Logo
P2, P3: Solder_Stencil_Alignment_Pin
Q1: BUK6D120-60PX; BUK6D12060PX
R1: 1K91; R_0603_1608Metric
R2: 2K; R_0805_2012Metric
R3: 100K; R_0603_1608Metric
R4: 31K6; R_0603_1608Metric
R5, R6, R10, R14: 10K; R_0603_1608Metric
R7, R11: 220K; R_0603_1608Metric
R8, R12: 42K2; R_0603_1608Metric
R9, R13: 28K; R_0603_1608Metric
R15: 365; R_0603_1608Metric
R16: 402; R_0603_1608Metric
R17, R18: 210; R_0603_1608Metric
R19, R20: 887; R_0603_1608Metric
S1, S2: Tactile Switch 6mm; PTS636SK25JSMTRLFS
TP1, TP2, TP3, TP4, TP5, TP6, TP7, TP8, TP9, TP10: TestPoint; TestPoint_THTPad_D1.0mm_Drill0.5mm
U1, U2, U3: TPS62130ARGTR; QFN50P300X300X100-17N-D
U4: STM32C011F4U6TR; UFQFPN20_3X3_STM
Z1: MMSZ5231B-7-F; SOD3716X145N

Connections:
/Input Power/GND: C1.2, C2.2, C3.2, C4.2, C5.1, C6.2, C7.2, C8.2, C9.1, C10.2, C11.2, C12.2, C13.1, C14.2, C15.2, CR1.2, J1.2, J2.5, J3.3, J3.4, J4.3, J4.4, R1.2, R2.2, R4.2, R9.2, R13.2, S1.1 (COM), S2.1 (COM), TP10.1, U1.6 (AGND), U1.8 (DEF), U1.15 (PGND_1), U1.16 (PGND_2), U1.17 (EP), U2.6 (AGND), U2.8 (DEF), U2.15 (PGND_1), U2.16 (PGND_2), U2.17 (EP), U3.6 (AGND), U3.8 (DEF), U3.15 (PGND_1), U3.16 (PGND_2), U3.17 (EP), U4.3 (VSS/VSSA)
/Input Power/RPPgate: Q1.3 (G), R1.1, Z1.2 (A)
/Input Power/VCC: C2.1, C3.1, C4.1, C7.1, C8.1, C11.1, C12.1, L1.2, LED1.1 (A), TP1.1, U1.10 (AVIN), U1.11 (PVIN_1), U1.12 (PVIN_2), U1.13 (EN), U2.10 (AVIN), U2.11 (PVIN_1), U2.12 (PVIN_2), U3.10 (AVIN), U3.11 (PVIN_1), U3.12 (PVIN_2)
/Input Power/Vfused: CR1.1, F1.2, Q1.1 (D_1), Q1.2 (D_2), Q1.5 (D_3), Q1.6 (D_4), Q1.7 (D_5)
/Input Power/Vin: F1.1, J1.1
/Input Power/Vprot: C1.1, L1.1, Q1.4 (S_1), Q1.8 (S_2), Z1.1 (K)
/MCU Control/3V3BLED_A: LED7.1 (A), R20.1
/MCU Control/3V3BLED_Sig: LED7.2 (K), U4.6 (PA1)
/MCU Control/3V3TLED_A: LED6.1 (A), R19.1
/MCU Control/3V3TLED_Sig: LED6.2 (K), U4.10 (PA5)
/MCU Control/5VBLED_A: LED5.1 (A), R18.1
/MCU Control/5VBLED_Sig: LED5.2 (K), U4.7 (PA2)
/MCU Control/5VTLED_A: LED4.1 (A), R17.1
/MCU Control/5VTLED_Sig: LED4.2 (K), U4.11 (PA6)
/MCU Control/Btn_Config: S2.2 (NO), U4.15 (PA12[PA10])
/MCU Control/Btn_OutputEn: S1.2 (NO), U4.18 (PB6)
/MCU Control/Enable_Output: TP7.1, U2.13 (EN), U3.13 (EN), U4.12 (PA7)
/MCU Control/ErrorLED_A: LED2.1 (A), R15.1
/MCU Control/ErrorLED_Sig: LED2.2 (K), U4.9 (PA4)
/MCU Control/NRST: J2.3, R14.2, U4.4 (PF2-NRST)
/MCU Control/OutputLED_A: LED3.1 (A), R16.1
/MCU Control/OutputLED_Sig: LED3.2 (K), U4.8 (PA3)
/MCU Control/PGood_RailB: R6.2, TP8.1, U3.4 (PG), U4.5 (PA0)
/MCU Control/PGood_RailT: R5.2, TP9.1, U2.4 (PG), U4.13 (PA8)
/MCU Control/SWDCLK: J2.4, U4.17 (PA14-BOOT0)
/MCU Control/SWDIO: J2.2, U4.16 (PA13)
/MCU Control/SelectVrailB: R12.2, R13.1, TP5.1, U4.19 (PB7)
/MCU Control/SelectVrailT: R8.2, R9.1, TP6.1, U4.14 (PA11[PA9])
/MCU Control/Vmcu: C6.1, C15.1, J2.1, L2.2, R3.1, R10.2, R14.1, R15.2, R16.2, R17.2, R18.2, R19.2, R20.2, TP2.1, U1.7 (FSW), U1.14 (VOS), U4.2 (VDD/VDDA)
/MCU Power Regulator/MCUReg_FB: R3.2, R4.1, U1.5 (FB)
/MCU Power Regulator/MCUReg_SS: C5.2, U1.9 (SS/TR)
/MCU Power Regulator/MCUReg_Sw_Out: L2.1, U1.1 (SW_1), U1.2 (SW_2), U1.3 (SW_3)
/MCU Power Regulator/PGood_MCU: R10.1, U1.4 (PG)
/Rail B Power Regulator/RailBReg_FB: R11.2, R12.1, U3.5 (FB)
/Rail B Power Regulator/RailBReg_SS: C13.2, U3.9 (SS/TR)
/Rail B Power Regulator/RailBReg_Sw_Out: L4.1, U3.1 (SW_1), U3.2 (SW_2), U3.3 (SW_3)
/Rail B Power Regulator/VrailB: C14.1, J4.1, J4.2, L4.2, R6.1, R11.1, TP4.1, U3.7 (FSW), U3.14 (VOS)
/Rail Output/VrailT: C10.1, J3.1, J3.2, L3.2, R5.1, R7.1, TP3.1, U2.7 (FSW), U2.14 (VOS)
/Rail T Power Regulator/RailTReg_FB: R7.2, R8.1, U2.5 (FB)
/Rail T Power Regulator/RailTReg_SS: C9.2, U2.9 (SS/TR)
/Rail T Power Regulator/RailTReg_Sw_Out: L3.1, U2.1 (SW_1), U2.2 (SW_2), U2.3 (SW_3)
unnamed: LED1.2 (K), R2.1

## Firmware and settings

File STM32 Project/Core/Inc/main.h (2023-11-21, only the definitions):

#define PGood_RailB_Pin GPIO_PIN_0
#define PGood_RailB_GPIO_Port GPIOA
#define LED_3V3B_Pin GPIO_PIN_1
#define LED_3V3B_GPIO_Port GPIOA
#define LED_5VB_Pin GPIO_PIN_2
#define LED_5VB_GPIO_Port GPIOA
#define LED_Output_Pin GPIO_PIN_3
#define LED_Output_GPIO_Port GPIOA
#define LED_Error_Pin GPIO_PIN_4
#define LED_Error_GPIO_Port GPIOA
#define LED_3V3T_Pin GPIO_PIN_5
#define LED_3V3T_GPIO_Port GPIOA
#define LED_5VT_Pin GPIO_PIN_6
#define LED_5VT_GPIO_Port GPIOA
#define Output_Enable_Pin GPIO_PIN_7
#define Output_Enable_GPIO_Port GPIOA
#define PGood_RailT_Pin GPIO_PIN_8
#define PGood_RailT_GPIO_Port GPIOA
#define Select_VRailT_Pin GPIO_PIN_11
#define Select_VRailT_GPIO_Port GPIOA
#define Btn_Config_Pin GPIO_PIN_12
#define Btn_Config_GPIO_Port GPIOA
#define Btn_OutputEn_Pin GPIO_PIN_6
#define Btn_OutputEn_GPIO_Port GPIOB
#define Select_VRailB_Pin GPIO_PIN_7
#define Select_VRailB_GPIO_Port GPIOB

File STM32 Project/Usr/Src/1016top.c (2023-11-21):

// Top file for project 1016
// Breadboard Power Supply

// Includes
#include "1016top.h"
#include "main.h"

// Private Variables
typeStMachPOSTRun stMachPOSTRun=stPowerOnDelay;
int stMachPOSTRunDelayCtr=0;
typeStMachConfig stMachConfig=st5T5B;
typeStMachInputButton stMachConfigButton=stNotPressed;
typeStMachInputButton stMachOutputButton=stNotPressed;
int stMachConfigBtnDebounceDelayCtr=0;
int stMachOutputBtnDebounceDelayCtr=0;
int stMachConfigBtnDetected=0;
int stMachOutputBtnDetected=0;
typeStMachOutput stMachOutput=stNotEnabled;
int stMachOutputWaitStableDelayCtr=0;
typeStMachError stMachError=stNoError;
int stMachErrorLEDBlinkCtr=0;
int stMachErrorLEDDelayCtr=0;

// Private Function Declarations
void POSTRunSM(void);
void ConfigButtonSM(void);
void ConfigSM(void);
void OutputButtonSM(void);
void OutputEnableMonitorSM(void);
void ErrorSM(void);

// Public Function Definitions
void _1016_TimerSetup(void) {
	// Start the main timer, this will call the ISR at 100 Hz (10 msec between calls)
	HAL_TIM_Base_Start_IT(&htim3);
}
void HAL_TIM_PeriodElapsedCallback(TIM_HandleTypeDef *htim) {
	// Check to make sure we've been called by the correct timer
	if (htim == &htim3) {
		// We've been called by the correct timer, begin processing

		// Process the POST/Run State machine first
		POSTRunSM();
		// If we're not in Run mode yet, nothing else can run, exit the ISR
		if (stMachPOSTRun!=stRun) return;

		// Process the Error State Machine next
		ErrorSM();
		// If the error state machine is in any state other than No Error, exit the ISR
		if (stMachError!=stNoError) return;

		// Process the Config Button Input State Machine
		ConfigButtonSM();

		// Process the Config State Machine
		ConfigSM();

		// Process the Output Button State Machine
		OutputButtonSM();

		// Process the Output Enable and Monitoring State Machine
		OutputEnableMonitorSM();
	}
}

// Private Functions
// POST/Run State Machine Function
void POSTRunSM(void) {
	// Handles the POST/Run state machine
	switch(stMachPOSTRun) {
		case stPowerOnDelay:
			// We're in the power-on delay period, wait 1 second (100 ticks)
			stMachPOSTRunDelayCtr++;
			// If 1 second has elapsed, advance state
			if (stMachPOSTRunDelayCtr>=100) {
				stMachPOSTRunDelayCtr=0;
				stMachPOSTRun=stLEDTest1;
			}
			break;
		case stLEDTest1:
			// Ready to test LED 1 (Top Rail 5V)
			stMachPOSTRunDelayCtr++;
			// If 0.25 second has elapsed, advance state
			if (stMachPOSTRunDelayCtr>=25) {
				stMachPOSTRunDelayCtr=0;
				HAL_GPIO_WritePin(LED_5VT_GPIO_Port, LED_5VT_Pin, GPIO_PIN_SET);
				stMachPOSTRun=stLEDTest2;
			} else
			{
				HAL_GPIO_WritePin(LED_5VT_GPIO_Port, LED_5VT_Pin, GPIO_PIN_RESET);
			}
			break;
		case stLEDTest2:
			// Ready to test LED 2 (Top Rail 3V3)
			stMachPOSTRunDelayCtr++;
			// If 0.25 second has elapsed, advance state
			if (stMachPOSTRunDelayCtr>=25) {
				stMachPOSTRunDelayCtr=0;
				HAL_GPIO_WritePin(LED_3V3T_GPIO_Port, LED_3V3T_Pin, GPIO_PIN_SET);
				stMachPOSTRun=stLEDTest3;
			} else
			{
				HAL_GPIO_WritePin(LED_3V3T_GPIO_Port, LED_3V3T_Pin, GPIO_PIN_RESET);
			}
			break;
		case stLEDTest3:
			// Ready to test LED 3 (Bottom Rail 5V)
			stMachPOSTRunDelayCtr++;
			// If 0.25 second has elapsed, advance state
			if (stMachPOSTRunDelayCtr>=25) {
				stMachPOSTRunDelayCtr=0;
				HAL_GPIO_WritePin(LED_5VB_GPIO_Port, LED_5VB_Pin, GPIO_PIN_SET);
				stMachPOSTRun=stLEDTest4;
			} else
			{
				HAL_GPIO_WritePin(LED_5VB_GPIO_Port, LED_5VB_Pin, GPIO_PIN_RESET);
			}
			break;
		case stLEDTest4:
			// Ready to test LED 4 (Bottom Rail 3V3)
			stMachPOSTRunDelayCtr++;
			// If 0.25 second has elapsed, advance state
			if (stMachPOSTRunDelayCtr>=25) {
				stMachPOSTRunDelayCtr=0;
				HAL_GPIO_WritePin(LED_3V3B_GPIO_Port, LED_3V3B_Pin, GPIO_PIN_SET);
				stMachPOSTRun=stLEDTest5;
			} else
			{
				HAL_GPIO_WritePin(LED_3V3B_GPIO_Port, LED_3V3B_Pin, GPIO_PIN_RESET);
			}
			break;
		case stLEDTest5:
			// Ready to test LED 5 (Output)
			stMachPOSTRunDelayCtr++;
			// If 0.25 second has elapsed, advance state
			if (stMachPOSTRunDelayCtr>=25) {
				stMachPOSTRunDelayCtr=0;
				HAL_GPIO_WritePin(LED_Output_GPIO_Port, LED_Output_Pin, GPIO_PIN_SET);
				stMachPOSTRun=stLEDTest6;
			} else
			{
				HAL_GPIO_WritePin(LED_Output_GPIO_Port, LED_Output_Pin, GPIO_PIN_RESET);
			}
			break;
		case stLEDTest6:
			// Ready to test LED 6 (Error)
			stMachPOSTRunDelayCtr++;
			// If 0.25 second has elapsed, advance state
			if (stMachPOSTRunDelayCtr>=25) {
				stMachPOSTRunDelayCtr=0;
				HAL_GPIO_WritePin(LED_Error_GPIO_Port, LED_Error_Pin, GPIO_PIN_SET);
				stMachPOSTRun=stPostLEDTestDelay;
			} else
			{
				HAL_GPIO_WritePin(LED_Error_GPIO_Port, LED_Error_Pin, GPIO_PIN_RESET);
			}
			break;
		case stPostLEDTestDelay:
			// Delay before entering Run mode, 1 second (100 ticks)
			stMachPOSTRunDelayCtr++;
			// If 1 second has elapsed, advance state
			if (stMachPOSTRunDelayCtr>=100) {
				stMachPOSTRunDelayCtr=0;
				stMachPOSTRun=stRun;
			}
			break;
		case stRun:
			// No action
			break;
	}
}
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

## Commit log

2023-10-08 V1.0.0.0
    Final version 1, sent for fabrication.
    [1016 Breadboard Power Supply-B_Cu.gbr, 1016 Breadboard Power Supply-B_Mask.gbr, 1016 Breadboard Power Supply-B_Paste.gbr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]
2023-10-23 v1.1.0.0
    Code bugs fixed and notes made for additional changes for version 2.
    [1016 Breadboard Power Supply.kicad_pcb, 1016 Parametric Solder Stencil Jig.3mf, 1016 Parametric Solder Stencil Jig.FCStd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]
2023-10-29 V1.1.0.1
    Created .private directory for private notes.
    [Master BOM.xlsx, Thermal Analysis.xlsx]
2023-10-30 v2.0.0.0
    1016 Breadboard Power Supply v2
    - Change FSW connection to the Vout on all regulators
    - Change regulator to TPS62130A so that PG pin goes low on thermal shutdown and UVLO
    - Change PG pullup to be a resistor at the regulator vice pullup within STM32 so that it can be actively discharged
    - Remove resistor across rail outputs for discharging to improve efficiency
    - Change board dimensions to correct span
    - Change pinout of STM32 for better routing
    - Change Tag-Connect footprint to momentary connection (no legs)
    - Make sure Tag-Connect footprint doesn't have solder paste layer
    - Added heat sinks on bottom under rail regulators, added thermal vias
    [1016 Breadboard Power Supply-B_Cu.gbr, 1016 Breadboard Power Supply-B_Mask.gbr, 1016 Breadboard Power Supply-B_Paste.gbr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]
2023-11-12 v2.0.0.1
    Version 2 Final
    [1016 Breadboard Power Supply.csv, 1016 Breadboard Power Supply.kicad_pcb, 1016 Parametric Solder Stencil Jig.3mf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]
2023-11-21 v2.1.0.0
    Full prototype, working 3D printed case.
    [1016 Case v1 No Text.FCStd, 1016 Case v2.FCStd, 1016 Parametric Solder Stencil Jig.3mf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]
2023-11-26 v2.1.1.0
    Add images, update README.md, remove old / backup / v1 files.
    [1016 Breadboard Power Supply JLCPCB.csv, 1016 Case v1 No Text.FCStd, Body - Button.stl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]

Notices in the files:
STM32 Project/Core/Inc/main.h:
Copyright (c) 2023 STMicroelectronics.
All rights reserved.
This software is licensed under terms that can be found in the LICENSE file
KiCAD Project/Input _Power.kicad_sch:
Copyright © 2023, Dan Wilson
